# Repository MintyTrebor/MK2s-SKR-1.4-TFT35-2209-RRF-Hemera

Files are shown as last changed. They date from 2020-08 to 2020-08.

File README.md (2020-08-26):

# MK2s-SKR-1.4-TFT35-2209-RRF-Hemera
A repo of all the parts, cad files, configurations for MK2s mods with SKR 1.4T + Hemera with only small loss of build volume.

_(This mod is created using modified original prusa parts and designs from thingiverse - please see attribution.txt for details.)_

A full set of modified files and firmware configuration for a set of mods to an original prusa MK2s. Parts that are not included in this repo have not been modified & therefore should be resourced from the orginal prusa repo.

**Mod Details:**
* Prusa MK2S original frame, bed, steppers, and power supply @12v  
* BTT SR 1.4 Turbo  
* BTT 2209 (Sensorless Homing is required as the modified parts do not allow for micro switches)  
* BTT TFT35  
* E3D Hemera  
* ANTCLABS BLT V3.1  

The modification reduces X,Y, & Z build volume X248 Y200 Z200 (There is some wiggle room in the Y & Z volume if you want to increase)

**Config Details:**
* RepRap Firmware with SBC (RPi) using mods from https://github.com/gloomyandy/RepRapFirmware  
* Additional Thermistor configured to monitor Chamber/Enclosure Temp  

**Other Info:**
All parts were printed on the MK2S using polycarbonate.

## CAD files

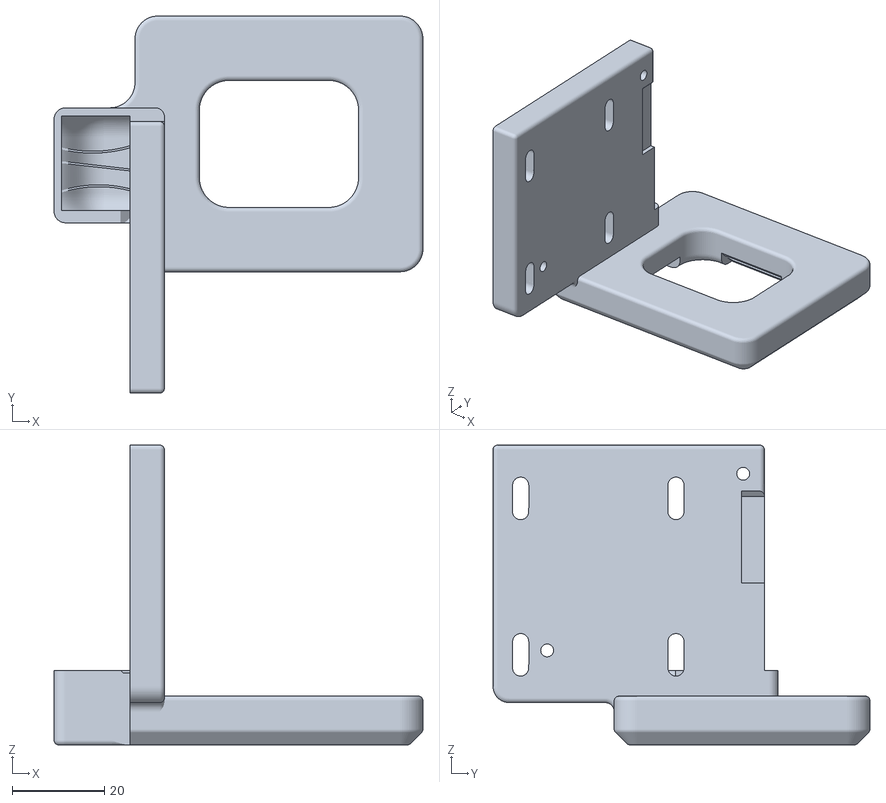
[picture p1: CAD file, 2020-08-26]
Hemera Cooling Fan v2.stl
80.2 x 81.9 x 65.2

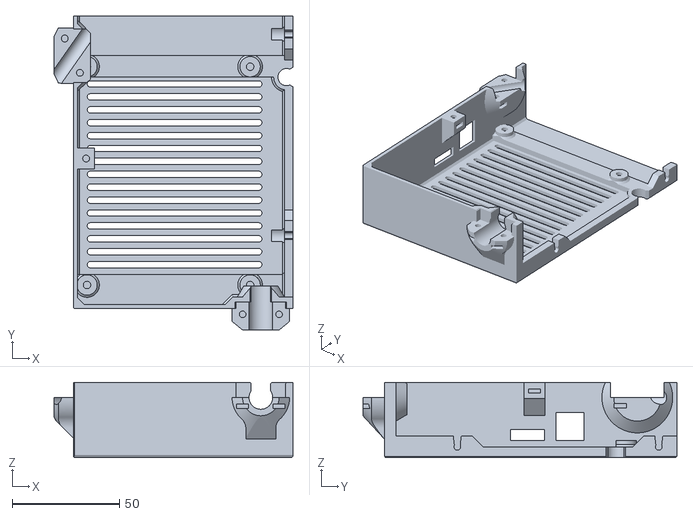
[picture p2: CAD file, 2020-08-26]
RamboCase/MK2 SKR 1.4 Base v2.stl
111.5 x 146.5 x 35.0

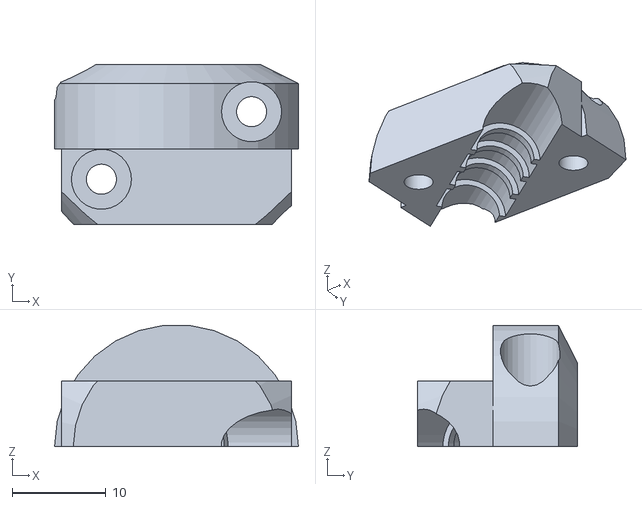
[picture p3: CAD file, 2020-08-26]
RamboCase/Heatbed-cable-clip.stl
26.0 x 17.0 x 12.9

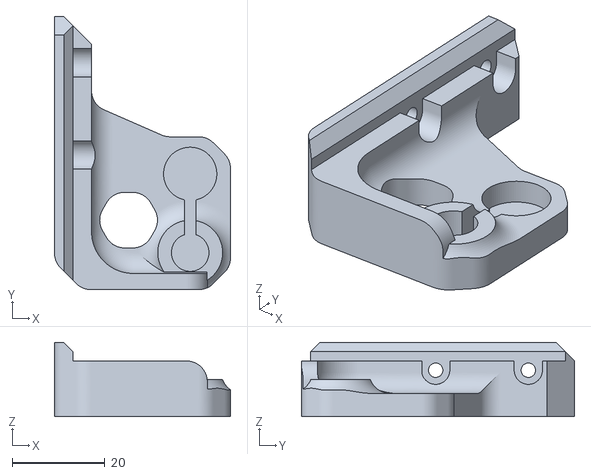
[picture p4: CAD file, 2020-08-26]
Z Top Mount Right v2.stl
38.0 x 59.0 x 16.0

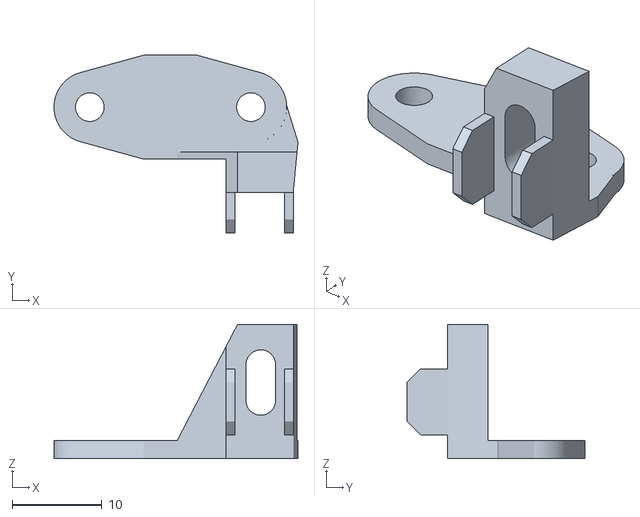
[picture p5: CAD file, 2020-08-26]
Hemera BLTouch Bracket.stl
27.3 x 19.8 x 15.0

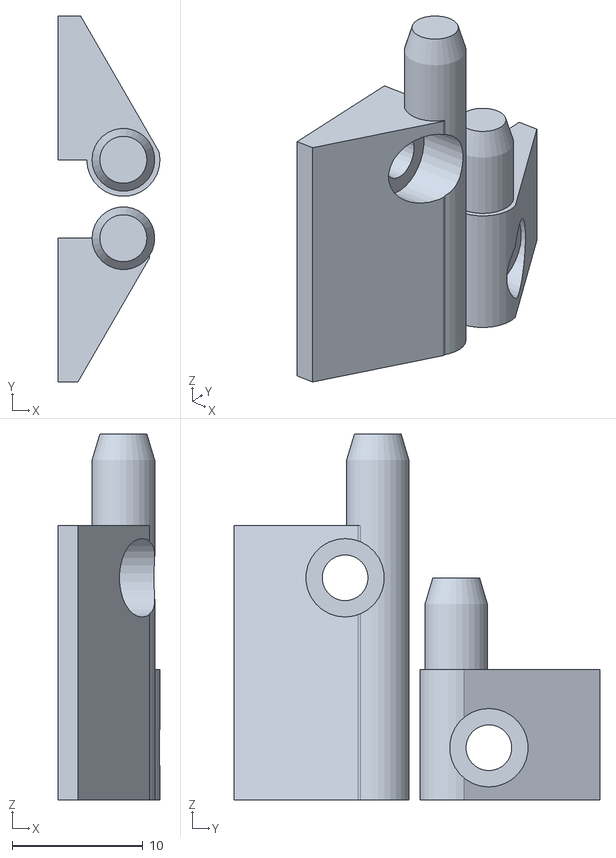
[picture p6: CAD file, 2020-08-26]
RamboCase/RAMBo_hinges.stl
7.80 x 28.0 x 28.0

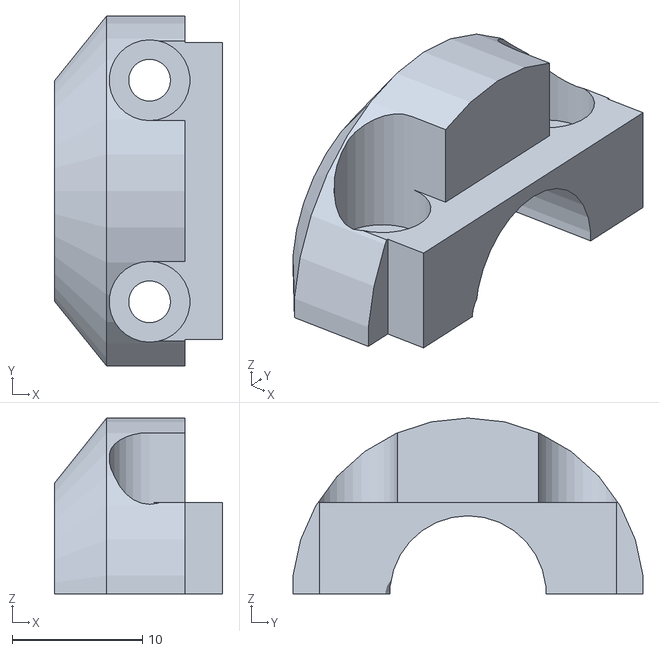
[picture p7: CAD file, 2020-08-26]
RamboCase/Extruder-cable-clip.stl
12.9 x 26.9 x 13.5

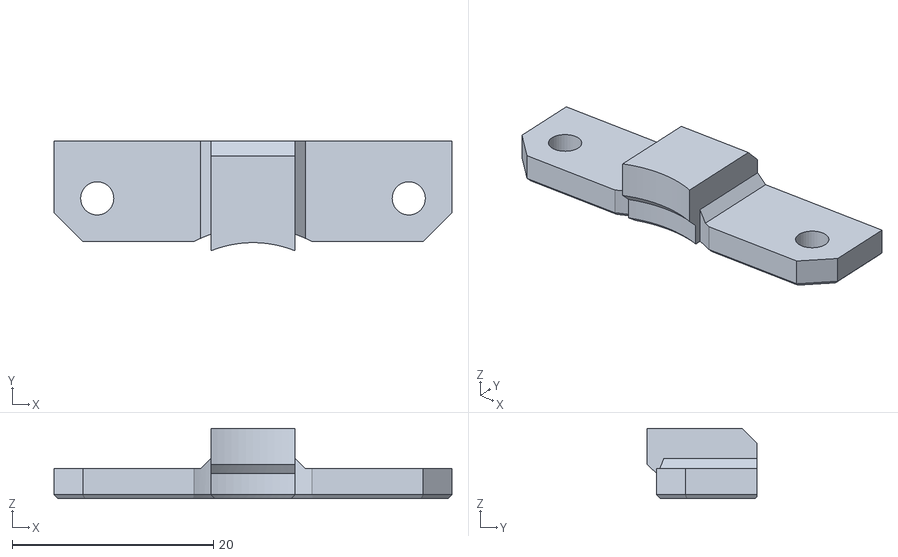
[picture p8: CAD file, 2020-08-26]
z_motor_mounts_fronts_V1.stl
39.6 x 10.9 x 7.00

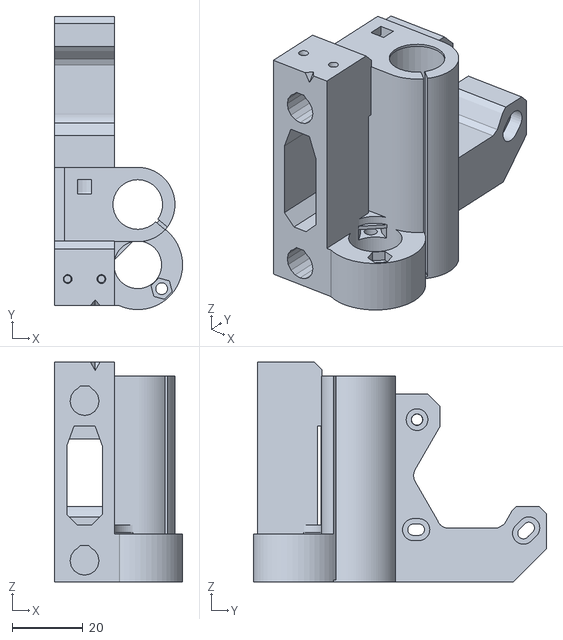
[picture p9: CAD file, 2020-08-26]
Mk2-R3-x-end-motor-w-switch (Print +1% xyz in PCarbonate).stl
36.1 x 82.6 x 62.0

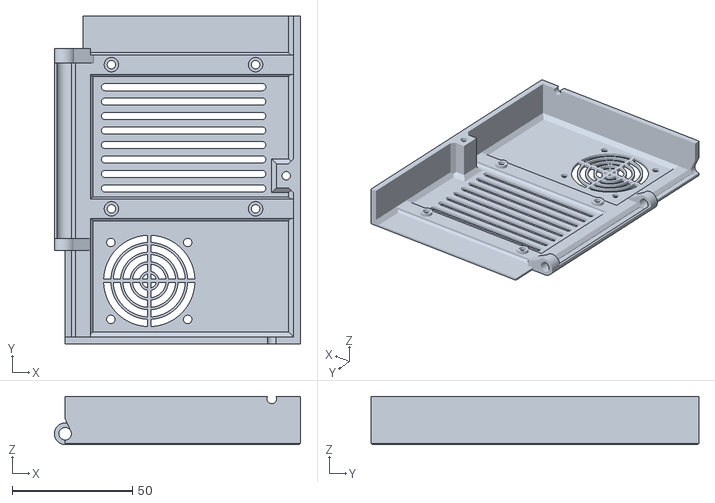
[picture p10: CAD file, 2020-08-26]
RamboCase/MK2 SKR 1.4 Door v2.stl
102.5 x 136.5 x 20.0

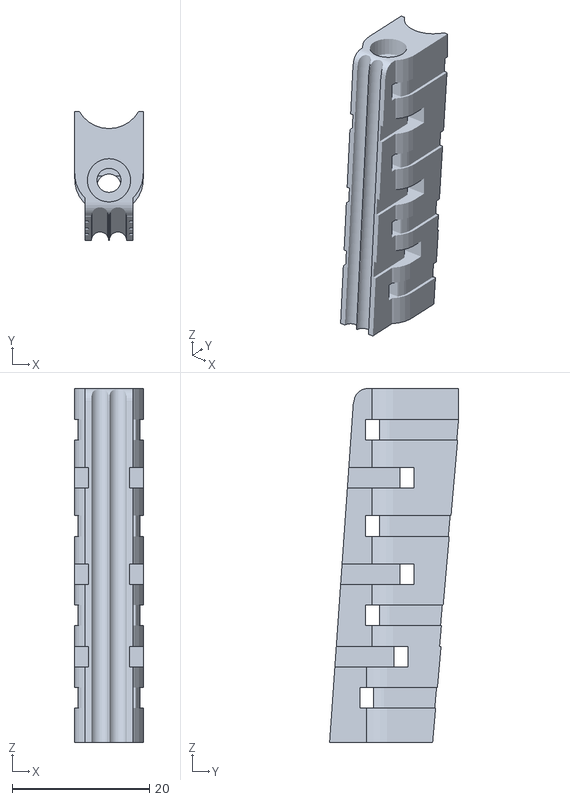
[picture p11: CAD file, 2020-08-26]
Cable Holder V2.stl
10.0 x 18.7 x 51.5

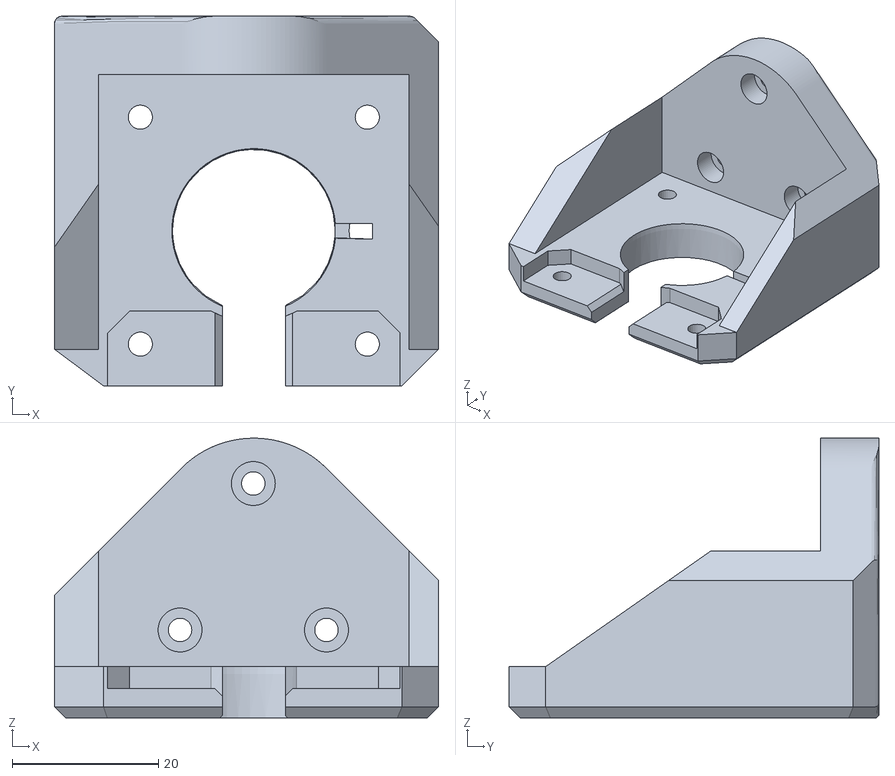
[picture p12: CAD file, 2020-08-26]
Z_Motor_Mount_Left v2.stl
52.5 x 50.5 x 38.2

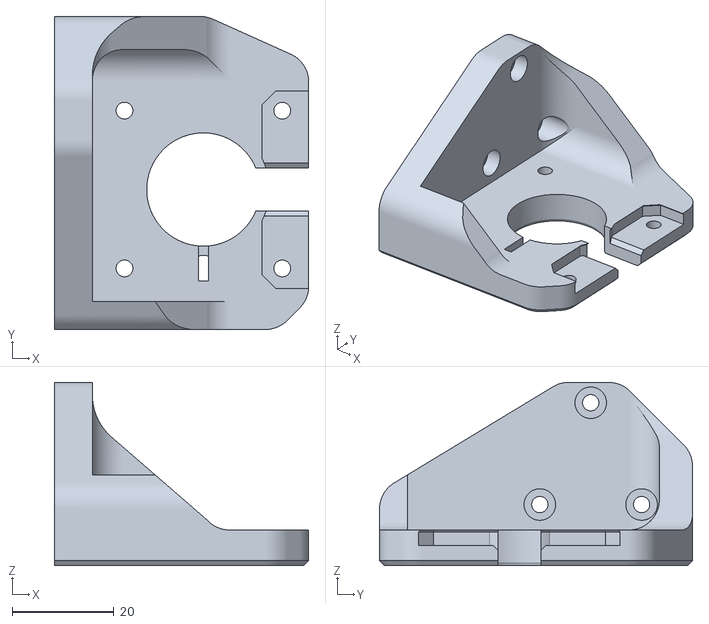
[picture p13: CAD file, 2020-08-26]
Z_Motor_Mount_Right v2.stl
50.0 x 61.5 x 36.0

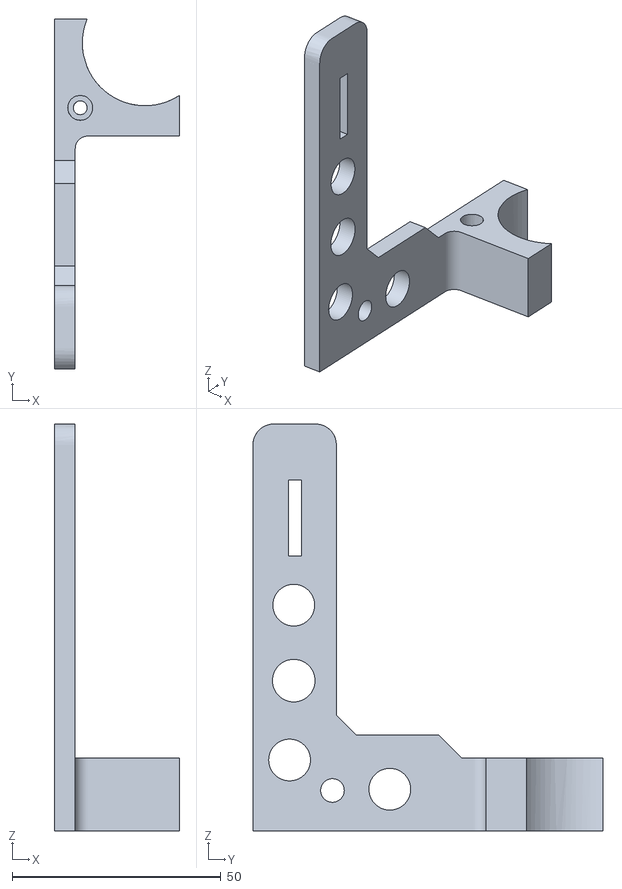
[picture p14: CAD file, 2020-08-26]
Camera Mount Z Axis.stl
30.0 x 83.9 x 97.4

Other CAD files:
MK3s_Hemera_Adapter_V3_plate.stl
x-carriage-back.stl
MK3s_Hemera_Adapter_v2_z_bottom_r.stl
Camera Plate.stl
BTT TFT35 Case v1.stl
BTT TFT35 LCD Support v1.stl
CAD Files/BLTouch Bracket.f3d
CAD Files/Cable Holder V2 v1.f3d
CAD Files/Part Cooler V2 v2.f3d
CAD Files/Z Cam Mount v2.f3d
CAD Files/Z Motor Mount Left v3.f3d
CAD Files/lcd-support v3.f3d
CAD Files/z_motor_mount_right.f3d
MK3s_Hemera_Adapter_v2_x_idler (Print +1% xyz in PCarbonate).stl
Z Top Mount Left v2.stl
cable-holder.stl
x-carriage.stl

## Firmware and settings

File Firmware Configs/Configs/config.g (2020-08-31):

; Configuration file for SKR v1.4 (firmware version 3)
; executed by the firmware on start-up
;
; generated by RepRapFirmware Configuration Tool v3.1.3-LPC-1 on Thu Aug 13 2020 09:40:16 GMT+0100 (British Summer Time)

; General preferences
G90                                            					; send absolute coordinates...
M83                                            					; ...but relative extruder moves
M550 P"mk2srrf"             									; set printer name

; Drives
M569 P0 S1 D3 V40                              					; physical drive 0 goes forwards using default driver timings
M569 P1 S1 D3 V40                              					; physical drive 1 goes forwards using default driver timings
M569 P2 S1 D3 V40                              					; physical drive 2 goes forwards using default driver timings
M569 P3 S1									   					; physical drive 3 goes forwards using default driver timings
M569 P4 S1 D3 V40                              					; physical drive 4 goes forwards using default driver timings
M584 X0 Y1 Z2:4 E3                            					; set drive mapping
M671 X-36:300 Y0:0 S1   					   					; set leadscrews potions (for z levelling)
M350 X16 Y16 Z16 E16 I1                        					; configure microstepping with interpolation
M92 X100.00 Y100.00 Z400.00 E397.00            					; set steps per mm
M566 X900.00 Y900.00 Z12.00 E120.00            					; set maximum instantaneous speed changes (mm/min)
M203 X12000.00 Y10000.00 Z1200.00 E7200.00     					; set maximum speeds (mm/min)
M201 X1250.00 Y1250.00 Z200.00 E10000.00       					; set accelerations (mm/s^2)
;M906 X800 Y650 Z550 E1197 I30                  				; set motor currents (mA) and motor idle factor in per cent
M906 X1100 Y850 Z750 E1197 I30                  				; set motor currents (mA) and motor idle factor in per cent
M84 S30                                        					; Set idle timeout

; Axis Limits
M208 X-1 Y-10 Z0 S1                            					; set axis minima
M208 X247 Y205 Z205 S0                         					; set axis maxima

; Endstops
M574 X1 S1 P"xstop"                           					; configure active-high endstop for low end on X via pin xstop
M574 Y2 S1 P"ystop"                           					; configure active-high endstop for high end on Y via pin ystop
M574 Z1 S2                                    					; configure Zstop as BLTouch

; Z-Probe (BLTouch)
M558 P9 H7 A2 B1 F100 S0.05 T6000 X0 Y0 Z1 C"^probe"       		; disable Z probe but set dive height, probe speed and travel speed
M950 S0 C"servo0"                              					; Setup servo 0 as servo port on SKR
G31 X-14.8 Y-42.7 Z1.99					   	   					; Probe Offset (3.725)

; Mesh Compenstion
M557 X18:232 Y5:162 S42:31                     					; define mesh grid
	
; Heaters
M308 S0 P"bedtemp" Y"thermistor" T100000 B4138 					; configure sensor 0 as thermistor on pin bedtemp
M950 H0 C"bed" T0                              					; create bed heater output on bed and map it to sensor 0
M307 H0 B0 S1.00                               					; disable bang-bang mode for the bed heater and set PWM limit
M140 H0                                        					; map heated bed to heater 0
M143 H0 S100                                   					; set temperature limit for heater 0 to 100C
;M308 S1 P"e0temp" Y"thermistor" T100000 B4138  				; configure sensor 1 as thermistor on pin e0temp
M308 S1 P"e0temp" Y"thermistor" T100000 B4725 C7.06e-8  		; configure sensor 1 as thermistor on pin e0temp
M950 H1 C"e0heat" T1                           					; create nozzle heater output on e0heat and map it to sensor 1
M307 H1 B0 S1.00                               					; disable bang-bang mode for heater  and set PWM limit
M308 S2 P"e1temp" Y"thermistor" A"Chamber Temp" T100000 B4138  	; configure sensor 2 as thermistor on pin e1temp

; Fans
M950 F0 C"fan0" Q500                           					; create fan 0 on pin fan0 and set its frequency
M106 P0 S0 H-1 C"Part Cooling"                 					; set fan 0 value. Thermostatic control is turned off
M950 F1 C"e1heat" T1                           					; create extruder fan output (2.4) on e1heat and map it to sensor 1 (T1)
M106 P1 R1 H1 T45 C"Hotend Cooling"            					; thermostatically 45C controlled fan from T1 sensor

; Tools
M563 P0 D0 H1 F0                               					; define tool 0
G10 P0 X0 Y0 Z0                                					; set tool 0 axis offsets
G10 P0 R0 S0                                   					; set initial tool 0 active and standby temperatures to 0C

; Miscellaneous
M575 P1 S3 B57600                              					; enable support for PanelDue (BTT TFT35)

M501

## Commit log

2020-08-26 Initial Upload
    Initial Upload
    [Align Z.g, BLTouch Bracket.f3d, Cable Holder V2 v1.f3d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]
2020-08-30 Small Config changes
    Added extra build volume, and tided up some of the configs
    [config.g, homeall.g, homex.g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]
2020-08-31 Stepper Current Updates
    Updated stepper currents as was using wrong values.
    [config-override.g, config.g]
